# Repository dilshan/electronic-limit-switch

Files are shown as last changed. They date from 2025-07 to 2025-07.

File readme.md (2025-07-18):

## Electronic Limit Switch

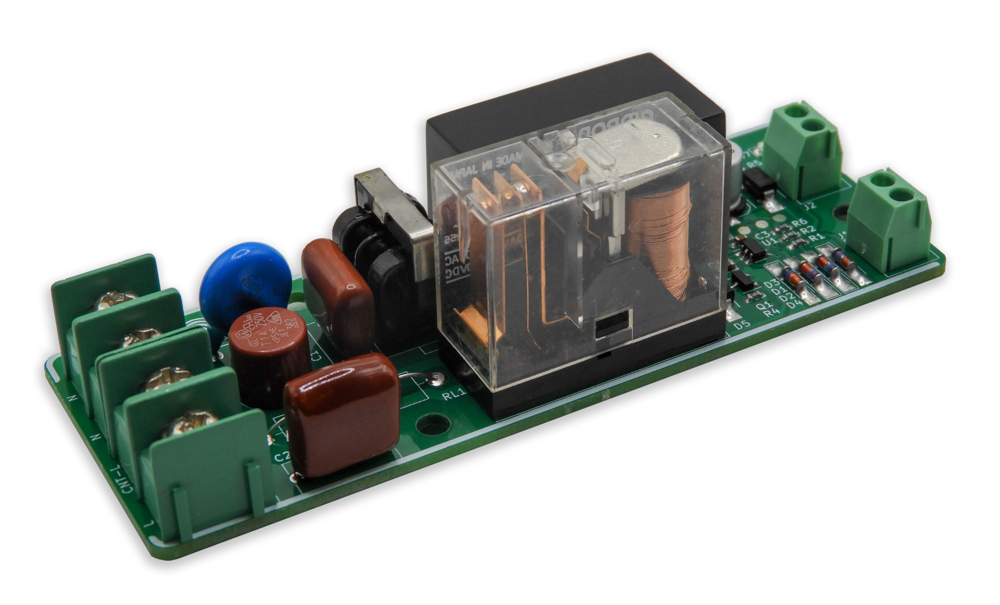
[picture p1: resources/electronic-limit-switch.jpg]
Prototype build of electronic limit switch.


This is an open-source fluid level control module designed for reliable and automated liquid management in tanks.

## Overview

This module can utilize two float-type limit switches or electronic sensor switches to detect fluid levels and control a relay accordingly. A microcontroller implements hysteresis logic to avoid unnecessary relay toggling caused by minor fluid level fluctuations, which enhances the system's reliability and lifespan.

## How it works

1. The module monitors two limit switches:
   - *Upper limit switch (J1)*: Closes when the fluid level falls below the upper threshold.
   - *Lower limit switch (J2)*: Closes when the fluid level rises above the lower threshold.

2. Based on these inputs, the onboard microcontroller:
   - Activates or deactivates the relay.
   - Applies hysteresis logic to prevent rapid toggling.

3. The *J4 terminal block* provides:
   - AC mains input (up to 240V).
   - Relay output for controlling pumps or other devices.

## License

This is a [certified open-source hardware project](https://certification.oshwa.org/lk000017.html). All [design files](https://github.com/dilshan/electronic-limit-switch/tree/main/design), [documentation](https://github.com/dilshan/electronic-limit-switch/wiki), and [firmware source code](https://github.com/dilshan/electronic-limit-switch/tree/main/firmware) are available for download at the project source repository. The content of this project is distributed under the following licenses:

- Hardware license: [CERN-OHL-W](https://opensource.org/license/cern-ohl-w)
- Software license: [MIT License](https://github.com/dilshan/electronic-limit-switch?tab=MIT-1-ov-file)
- Documentation license: [CC BY 4.0](https://creativecommons.org/licenses/by/4.0)

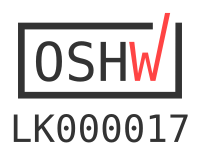
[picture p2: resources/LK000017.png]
LK000017 (https://certification.oshwa.org/lk000017.html)


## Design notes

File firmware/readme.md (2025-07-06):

The [project's documentation](https://github.com/dilshan/electronic-limit-switch/wiki) contains details on how to compile and flash the firmware.

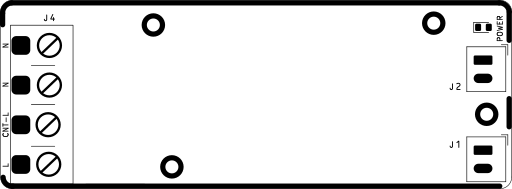
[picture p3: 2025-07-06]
resources/electronic-limit-sw-brd-top.png

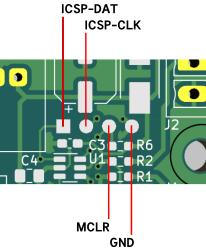
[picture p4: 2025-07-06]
resources/ICSP-pinout.png

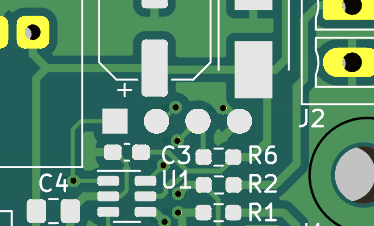
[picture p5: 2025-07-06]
resources/ICSP-pinout-pcb.png

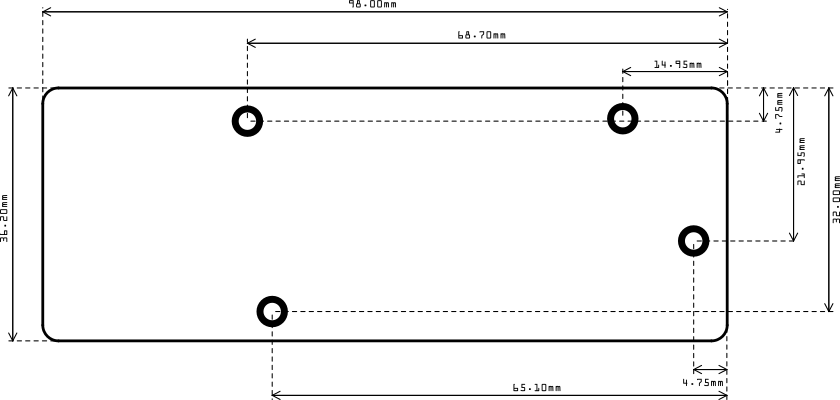
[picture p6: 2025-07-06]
resources/electronic-limit-sw-brd-dim.png

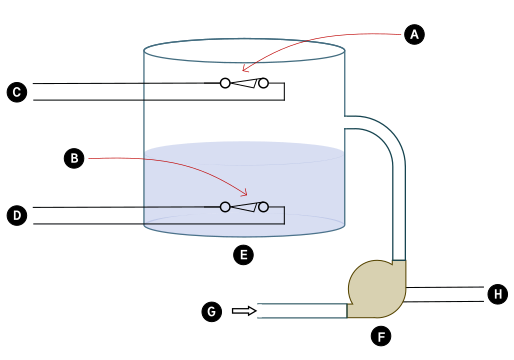
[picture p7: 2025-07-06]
resources/water-pump-layout.png

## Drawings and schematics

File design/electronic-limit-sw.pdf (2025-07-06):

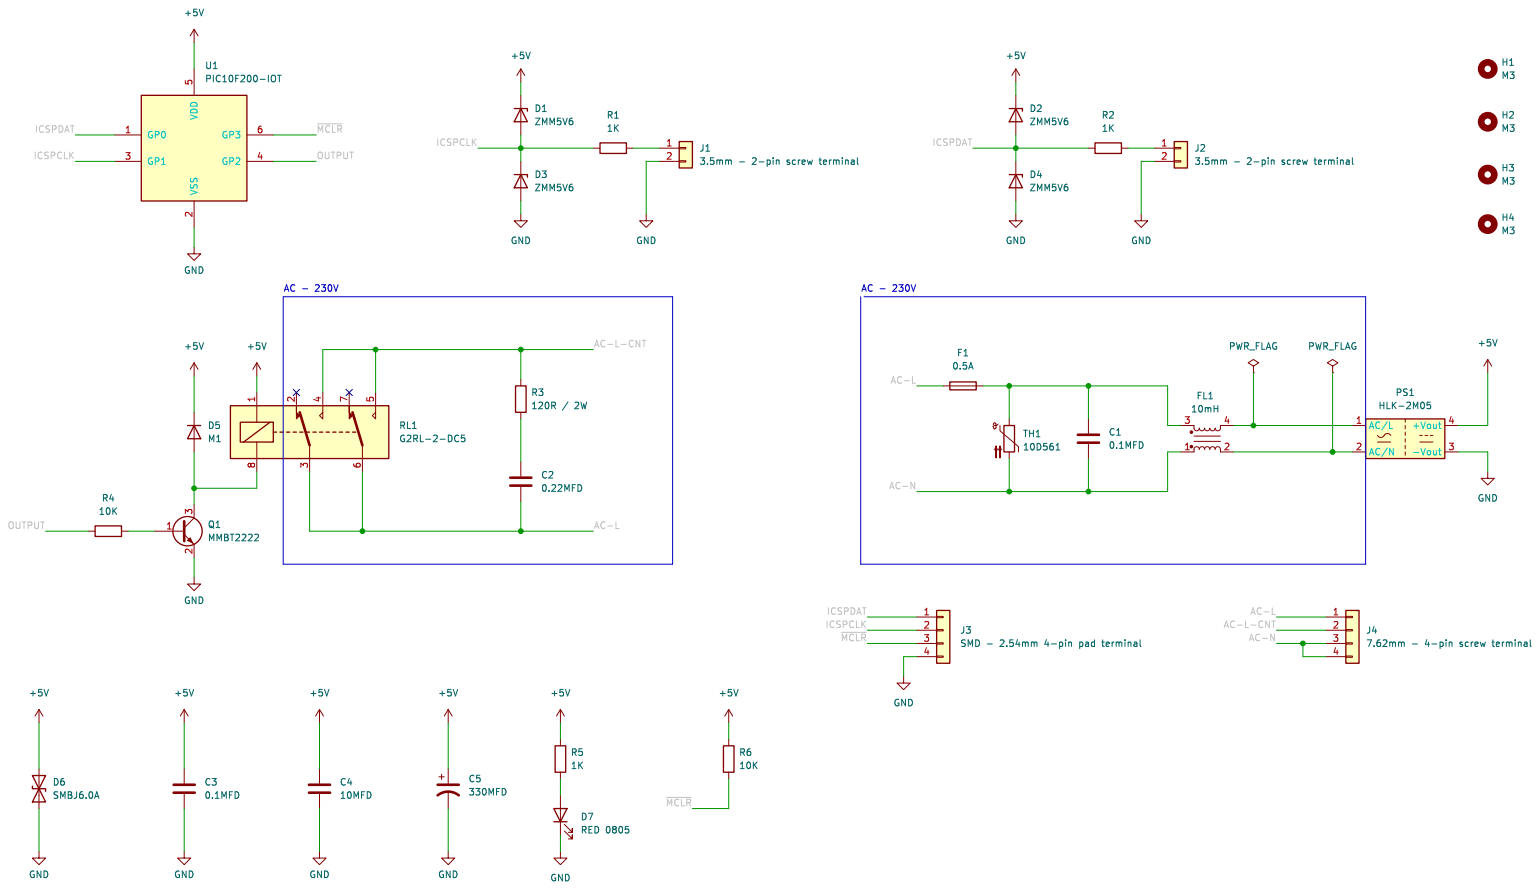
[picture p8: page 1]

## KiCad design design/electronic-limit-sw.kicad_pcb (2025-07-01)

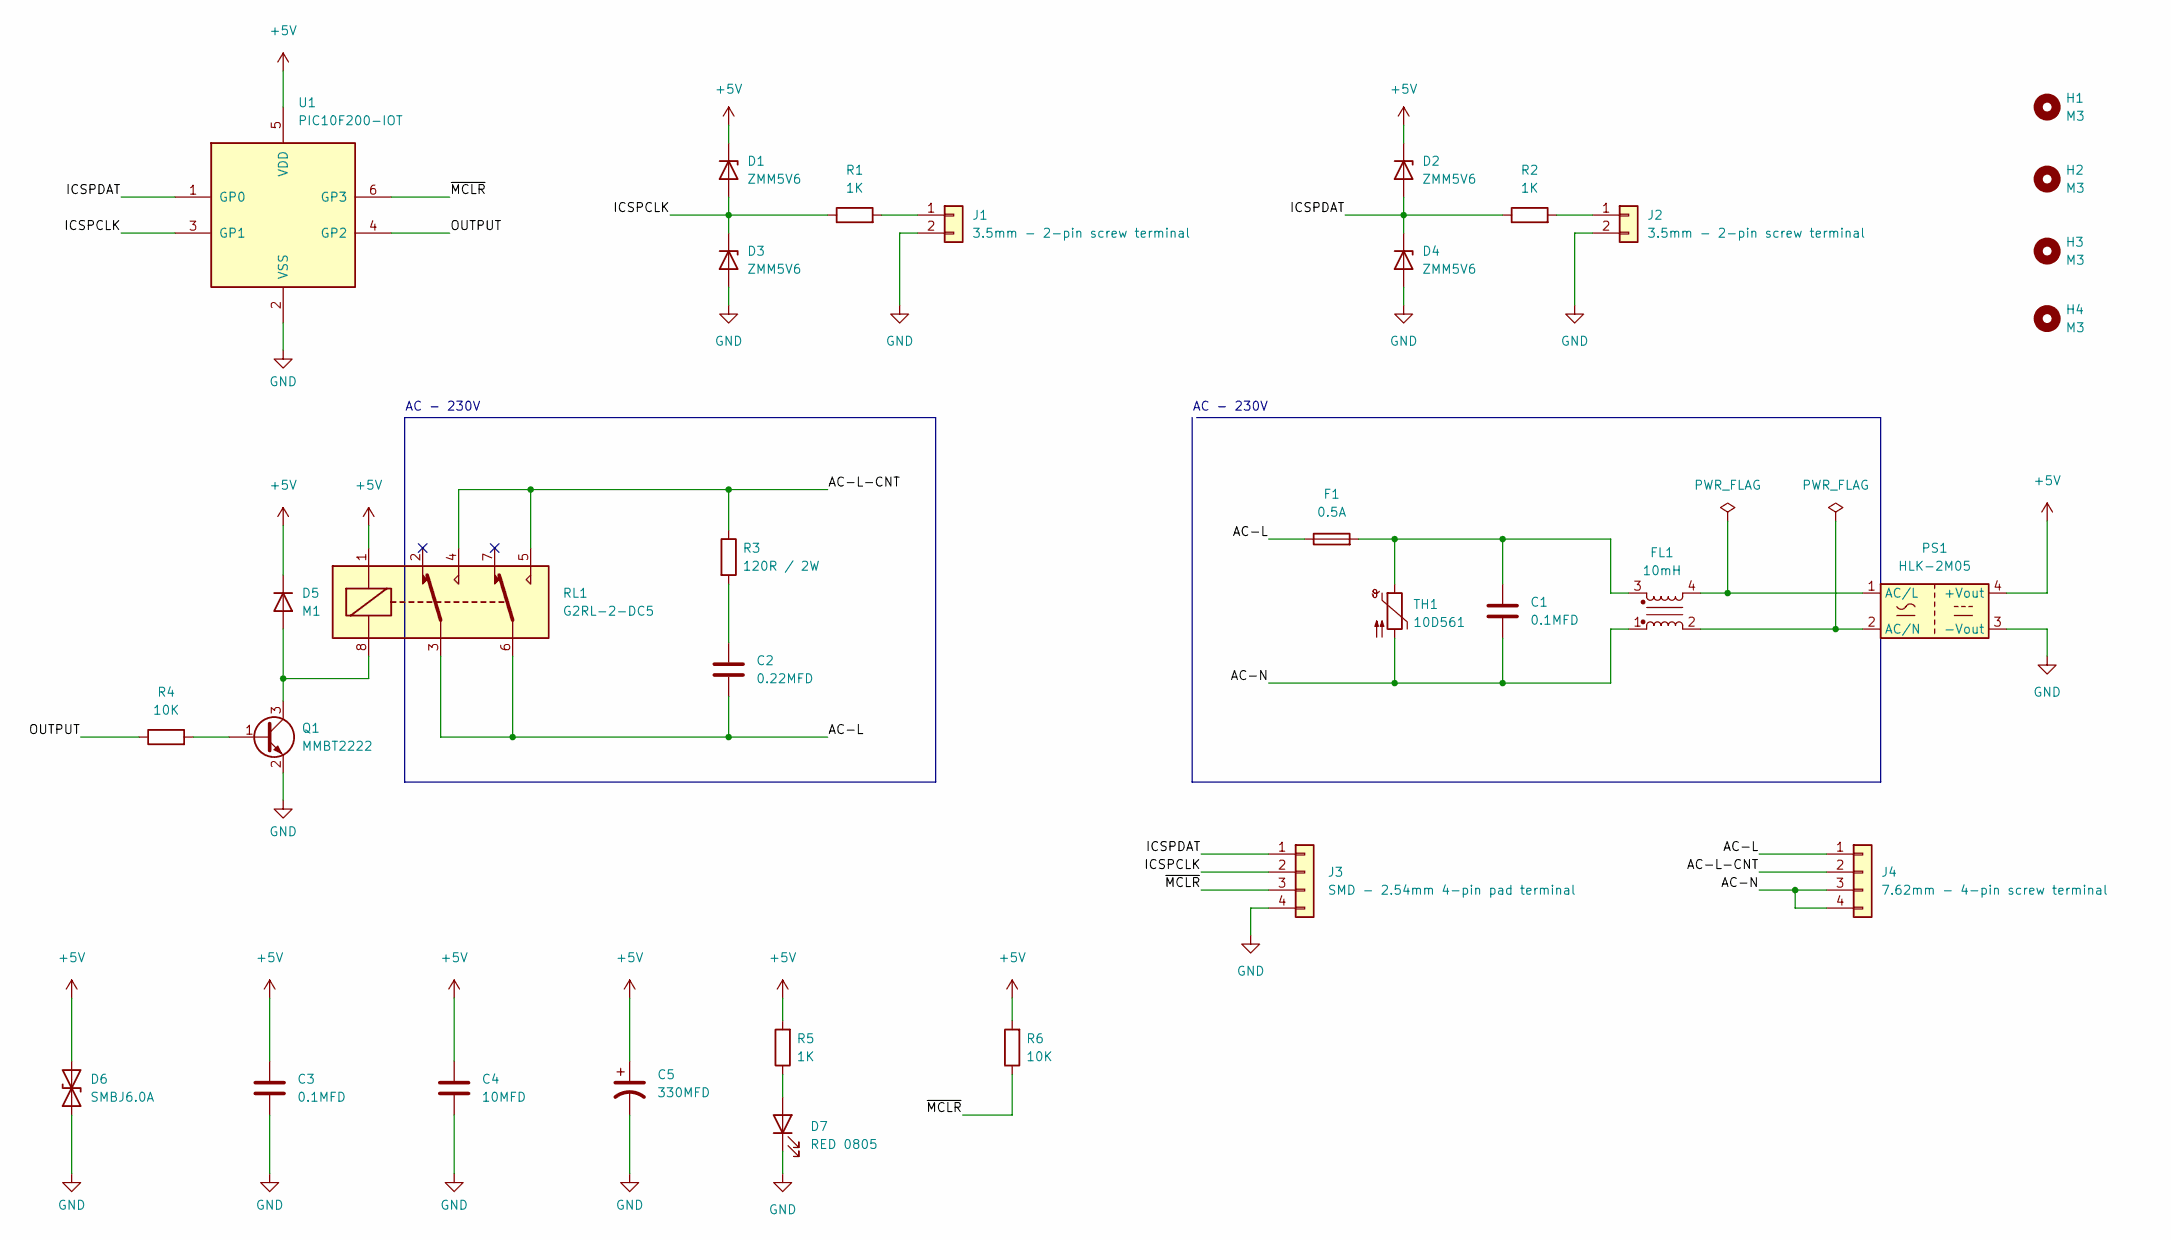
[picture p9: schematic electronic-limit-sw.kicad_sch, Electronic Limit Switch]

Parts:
C1: 0.1MFD; C_Rect_L11.0mm_W4.3mm_P10.00mm_MKT
C2: 0.22MFD; C_Rect_L11.0mm_W5.1mm_P10.00mm_MKT
C3: 0.1MFD; C_0603_1608Metric_Pad1.08x0.95mm_HandSolder
C4: 10MFD; C_0805_2012Metric_Pad1.18x1.45mm_HandSolder
C5: 330MFD; CP_Elec_6.3x7.7
D1, D2, D3, D4: ZMM5V6; D_MiniMELF_Handsoldering
D5: M1; D_SMA_Handsoldering
D6: SMBJ6.0A; D_SMB_Handsoldering
D7: RED 0805; LED_0805_2012Metric_Pad1.15x1.40mm_HandSolder
F1: 0.5A; Fuse_Littelfuse_372_D8.50mm
FL1: 10mH; CM-Choke-15.5mmx10.9mm
H1, H2, H3, H4: M3; MountingHole_3.5mm
J1, J2: 3.5mm - 2-pin screw terminal; PhoenixContact_MCV_1,5_2-G-3.5_1x02_P3.50mm_Vertical
J3: SMD - 2.54mm 4-pin pad terminal; pogo-2.54mmx4
J4: 7.62mm - 4-pin screw terminal; Screw-Terminal-4Way-7.62mm
PS1: HLK-2M05; PSU-Module-10.5mmx16.5mm
Q1: MMBT2222; SOT-23-3
R1, R2, R5: 1K; R_0603_1608Metric_Pad0.98x0.95mm_HandSolder
R3: 120R / 2W; R_Axial_DIN0516_L15.5mm_D5.0mm_P20.32mm_Horizontal
R4, R6: 10K; R_0603_1608Metric_Pad0.98x0.95mm_HandSolder
RL1: G2RL-2-DC5; Relay_DPDT_Omron_G2RL
TH1: 10D561; RV_Disc_D12mm_W4.2mm_P7.5mm
U1: PIC10F200-IOT; SOT-23-6

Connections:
+5V: C3.1, C4.1, C5.1, D1.1 (K), D2.1 (K), D5.1 (K), D6.2 (A2), PS1.4 (+Vout), R5.2, R6.2, RL1.1, U1.5 (VDD)
/AC-L: C2.2, F1.1, J4.1, RL1.3, RL1.6
/AC-L-CNT: J4.2, R3.1, RL1.4, RL1.5
/AC-N: C1.2, FL1.1, J4.3, J4.4, TH1.2
/ICSPCLK: D1.2 (A), D3.1 (K), J3.2, R1.1, U1.3 (GP1)
/ICSPDAT: D2.2 (A), D4.1 (K), J3.1, R2.1, U1.1 (GP0)
/OUTPUT: R4.1, U1.4 (GP2)
/~MCLR: J3.3, R6.1, U1.6 (GP3)
GND: C3.2, C4.2, C5.2, D3.2 (A), D4.2 (A), D6.1 (A1), D7.1 (K), J1.2, J2.2, J3.4, PS1.3 (-Vout), Q1.2 (E), U1.2 (VSS)
unnamed: C1.1, F1.2, FL1.3, TH1.1
unnamed: C2.1, R3.2
unnamed: D5.2 (A), Q1.3 (C), RL1.8
unnamed: D7.2 (A), R5.1
unnamed: J1.1, R1.2
unnamed: J2.1, R2.2
unnamed: FL1.4, PS1.1 (AC/L)
unnamed: FL1.2, PS1.2 (AC/N)
unnamed: Q1.1 (B), R4.2

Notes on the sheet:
AC - 230V

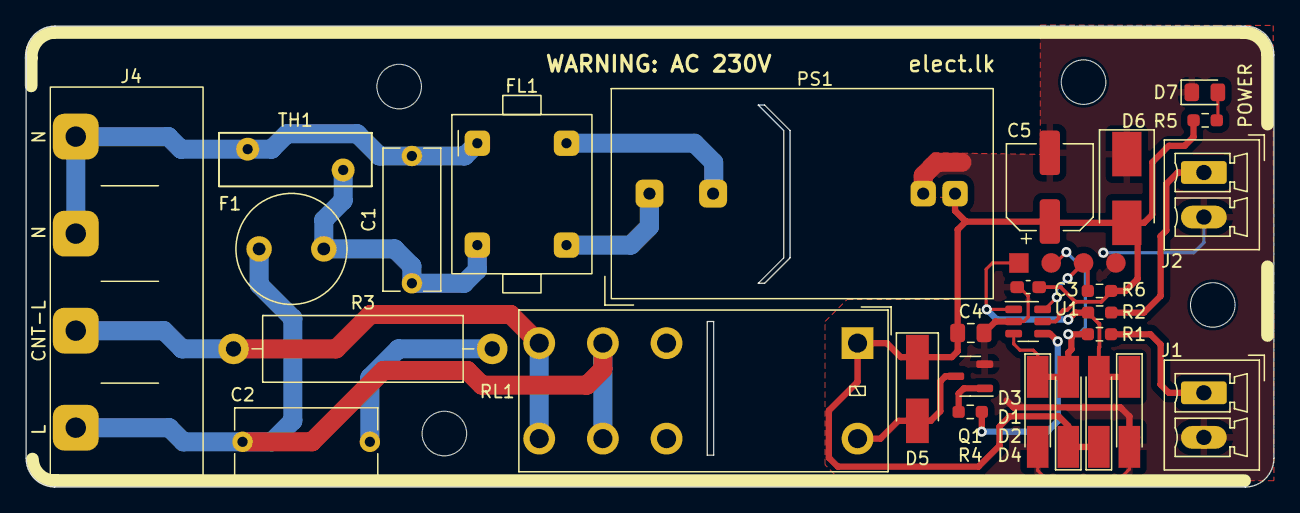
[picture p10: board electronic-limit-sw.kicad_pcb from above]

Board: 2 copper layers, 98.0 x 36.2 mm, 33 parts (0 on the bottom side), 18 nets.

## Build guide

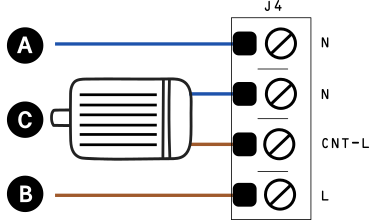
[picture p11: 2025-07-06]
resources/electronic-limit-sw-wiring-v2.png

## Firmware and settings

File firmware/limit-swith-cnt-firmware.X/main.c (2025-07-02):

/*********************************************************************************
 * Copyright (c) 2025 Dilshan R Jayakody [jayakody2000lk@gmail.com].
 *
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
 * THE SOFTWARE IS PROVIDED "AS IS", WITHOUT WARRANTY OF ANY KIND, EXPRESS OR
 * IMPLIED, INCLUDING BUT NOT LIMITED TO THE WARRANTIES OF MERCHANTABILITY,
 * FITNESS FOR A PARTICULAR PURPOSE AND NONINFRINGEMENT. IN NO EVENT SHALL THE
 * AUTHORS OR COPYRIGHT HOLDERS BE LIABLE FOR ANY CLAIM, DAMAGES OR OTHER
 * LIABILITY, WHETHER IN AN ACTION OF CONTRACT, TORT OR OTHERWISE, ARISING FROM,
 * OUT OF OR IN CONNECTION WITH THE SOFTWARE OR THE USE OR OTHER DEALINGS IN THE
 * SOFTWARE.
 *********************************************************************************/

#include "config.h"

#include <xc.h>

#define CHANGE_COUNTER_START    11

void applyRelayOutput()
{
  if((GPIO & 0x03) == 0x03)
  {
      NOP();
      NOP();
      GPIO = 0x00;
  }
  else
  {
      NOP();
      NOP();
      GPIO = 0x04;
  }
}

void main(void) 
{
  unsigned char initalState;
  char changeCounter;
  
  // Initialize system registers and peripherals.
  OPTION = 0x97;
  
  // Initialize GPIO ports. 
  // GP0 - [IN]  - Switch 1 (Lower limit)
  // GP1 - [IN]  - Switch 2 (Upper limit)
  // GP2 - [OUT] - Relay
  TRISGPIO = 0x03;
  GPIO = 0x00;
  
  initalState = (GPIO & 0x03);
  changeCounter = CHANGE_COUNTER_START;
  
  // Main service loop.
  while(1)
  {
    if((GPIO & 0x03) != initalState)
    {
      // Change has detected on limit switches and start counter.        
      changeCounter = CHANGE_COUNTER_START;
    }
    
    if(changeCounter > 0)
    {
      changeCounter--;
      if(changeCounter <= 1)
      {
        // The change counter timeout has reached, apply output changes.
        applyRelayOutput();
        changeCounter = 0;
      }
    }
    
    initalState = (GPIO & 0x03);
    __delay_ms(100);
  }
    
  return;
}

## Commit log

2024-01-12 Add new Simtelic logo and update version.
    [electronic-limit-sw.kicad_pcb, electronic-limit-sw.kicad_sch]
2024-01-12 Add gerber files for production [12/01/2024]
    [electronic-limit-sw-B_Cu.gbr, electronic-limit-sw-B_Mask.gbr, electronic-limit-sw-B_Paste.gbr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]
2025-07-01 Upgrade project to new KiCAD version.
    [electronic-limit-sw-B_Cu.gbr, electronic-limit-sw-B_Mask.gbr, electronic-limit-sw-B_Paste.gbr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]
2025-07-06 Add schematic in PDF format.
2025-07-06 Add picture of prototype build into readme file.
